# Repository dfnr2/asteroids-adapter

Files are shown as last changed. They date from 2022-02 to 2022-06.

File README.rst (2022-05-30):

Asteroids PCB -> Asteroids Deluxe Cabinet (and vice versa) Adapter
==================================================================

Background
----------

It is occasionally desirable to use an Asteroids PCB in an Asteroids Deluxe
cabinet (or vice versa). For example, the Braze Asteroids Multigame adapter
offers some advantages over the Asteroids Deluxe version of the multigame, such
as more accurate sound, and a Lunar Lander thruster interface. Or one may want
to use an Asteroids cabinet for testing both Asteroids and Asteroids Deluxe
PCBs. Or one may prefer the aesthetics of one cabinet, but the gameplay of the
other PCB.

The Asteroids PCB is almost compatible with the Asteroids Deluxe cabinet (and
vice versa). There are a few differences that must be addressed for an Asteroids
PCB to properly work in an Asteroids Deluxe cabinet:

#. The Deluxe cabinet uses a mirror to produce a floating 3D effect, which has the
   side effect of inverting the image along the Y axis, so Asteroids Y output needs
   to be inverted to properly work on an Asteroids Deluxe cabinet.

#. The Y-axis flip is only true for full standup cabinets. An Asteroids in an
   Asteroids Deluxe Cabaret does not require a flip.

#. The audio amplifier board in the Asteroids Deluxe PCB (A/R 1 board) has a
   voltage gain of 1, while the amplifier in the original Asteroids cabinet (A/R
   board) has a voltage gain of 10. As a result, the Asteroids PCB audio output
   is 1/10 the amplitude of the Asteroids Deluxe PCB, and will be much to quiet.
   The Asteroids audio output needs to be amplified by a factor of 10 to sound
   right.

#. Several control inputs are swapped.  These are:

   - COINL (left coin switch) and START2 (2-player START)

   - COINC (center coin switch) and START1 (1-player START)

   - ROT L (Rotate Left) and ROT R (Rotate Right)

For using an Asteroids Deluxe PCB in an Asteroids cabinet, There is a slightly
different set of considerations:

#. The Asteroids cabinet does not ground the INV_Y input of the Asteroids Deluxe
   PCB, since the Asteroids PCB has no INV_Y input. Therefore, the Y output is
   not inverted, and does not need to be re-inverted by the cabinet.

#. The Astroids Deluxe audio output amplitude will be too large, and needs to be
   divided by 10 to sound correct in an Asteroids cabinet.

#. The control inputs need to be flipped the same as for an Asteroids PCB in an
   Asteroids Cabinet.

The Adapter
-----------

.. _production_package: https://github.com/dfnr2/asteroids-adapter/tree/main/production-package/

The adapter was created with KiCad 6.0.5. KiCad was used because it is freely
available and multi-platform. The adapter design files are in the top directory.
For those who wish to produce the PCB without installing KiCad, a ZIP file is
available in the production_package_ directory.

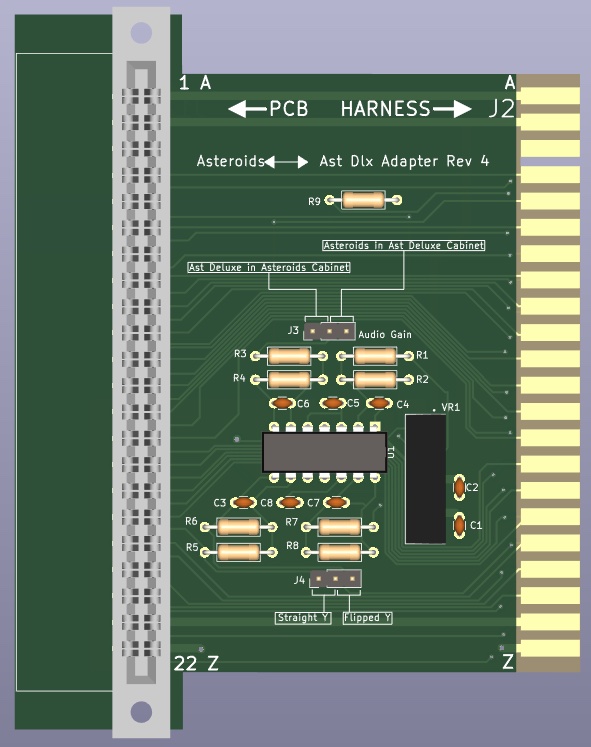
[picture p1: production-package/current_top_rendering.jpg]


Assembly Notes
--------------

The PCB is designed to accomodate a variety of 44-pin edge connectors, so that almost any standard 0.156" connector will work.

- Vertical (straight) edge connectors (such as EDAC 305-044-521-202) can be
  sourced cheaply and are readily available. With a vertical connector, the
  adapter will be perpendicular to the Asteroids PCB.

- A Right-angle edge connector (such as EDAC 307-044-558-201) can be used to
  keep the adapter parallel and aligned the Asteroids PCB. These connectors are
  in production, but as far as I know are only available from EDAC, and could
  potentially be subject to supply chain issues.

Configuration
-------------

The asteroids adapter will accommodate either an Asteroids PCB in an Asteroids
Deluxe Cabinet, or an Asteroids Deluxe PCB in an Asteroids cabinet.

For Asteroids in a Deluxe cabinet, set the jumpers as follows:

- J3 (Audio gain): Asteroids in Ast Dlx Cabinet (10x gain)

- J4 (Y Flip): Flipped Y

For Asteroids Deluxe in an Asteroids cabinet, set the jumpers as follows:

- J3 (Audio gain): Ast Dlx in Asteroids Cabinet (0.1x gain)

- J4 (Y Flip): Straight Y

For Asteroids in an Asteroids Deluxe cabaret cabinet (not tested):

- J3 (Audio gain): Asteroids in Ast Dlx Cabinet (10x gain)

- J4 (Y Flip): Straight Y

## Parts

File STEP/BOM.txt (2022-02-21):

3DX_CUI_Supplier: CUI, Inc
3DX_CUI_Description: 15 Vdc, 0.067 A, 1 W, 4.5 ~ 5.5 Vdc Input Range
3DX_CUI_Model Number: PESE1-S5-S15-M

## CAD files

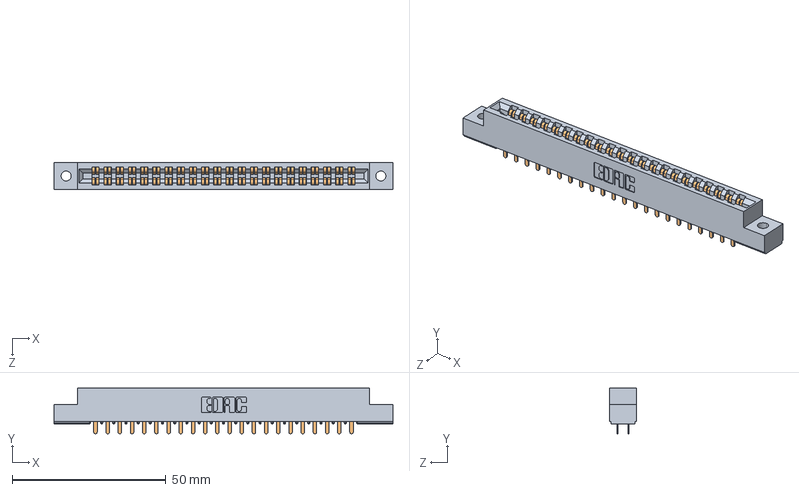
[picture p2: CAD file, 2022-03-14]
STEP/EDAC-305-44-0521-202.STEP
110.2 x 14.9 x 8.71 mm
305 Part_.128 Dia

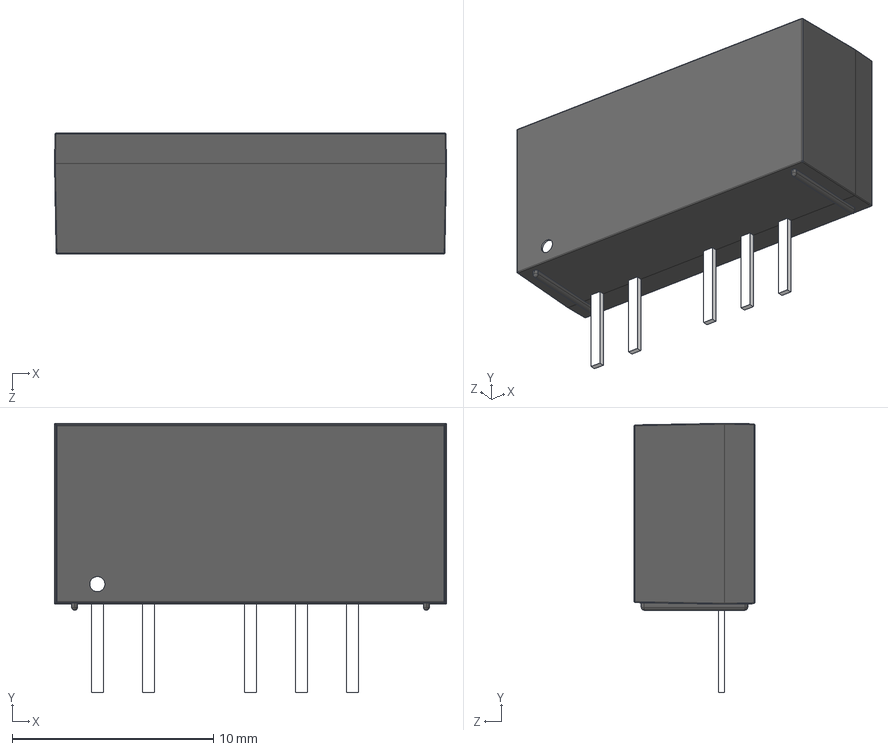
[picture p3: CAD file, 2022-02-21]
STEP/PDM1-S5-D15-S.step
19.5 x 13.4 x 6.00 mm

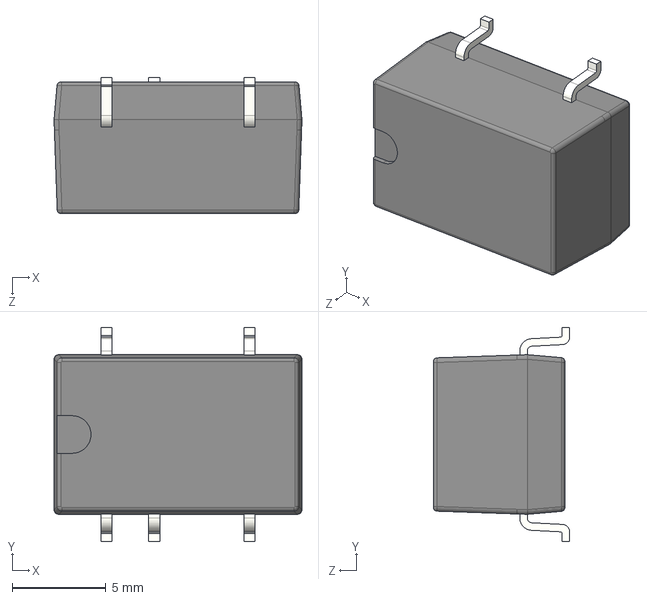
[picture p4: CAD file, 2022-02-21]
STEP/CUI_PESE1-S5-S15-M.step
13.2 x 11.4 x 7.25 mm

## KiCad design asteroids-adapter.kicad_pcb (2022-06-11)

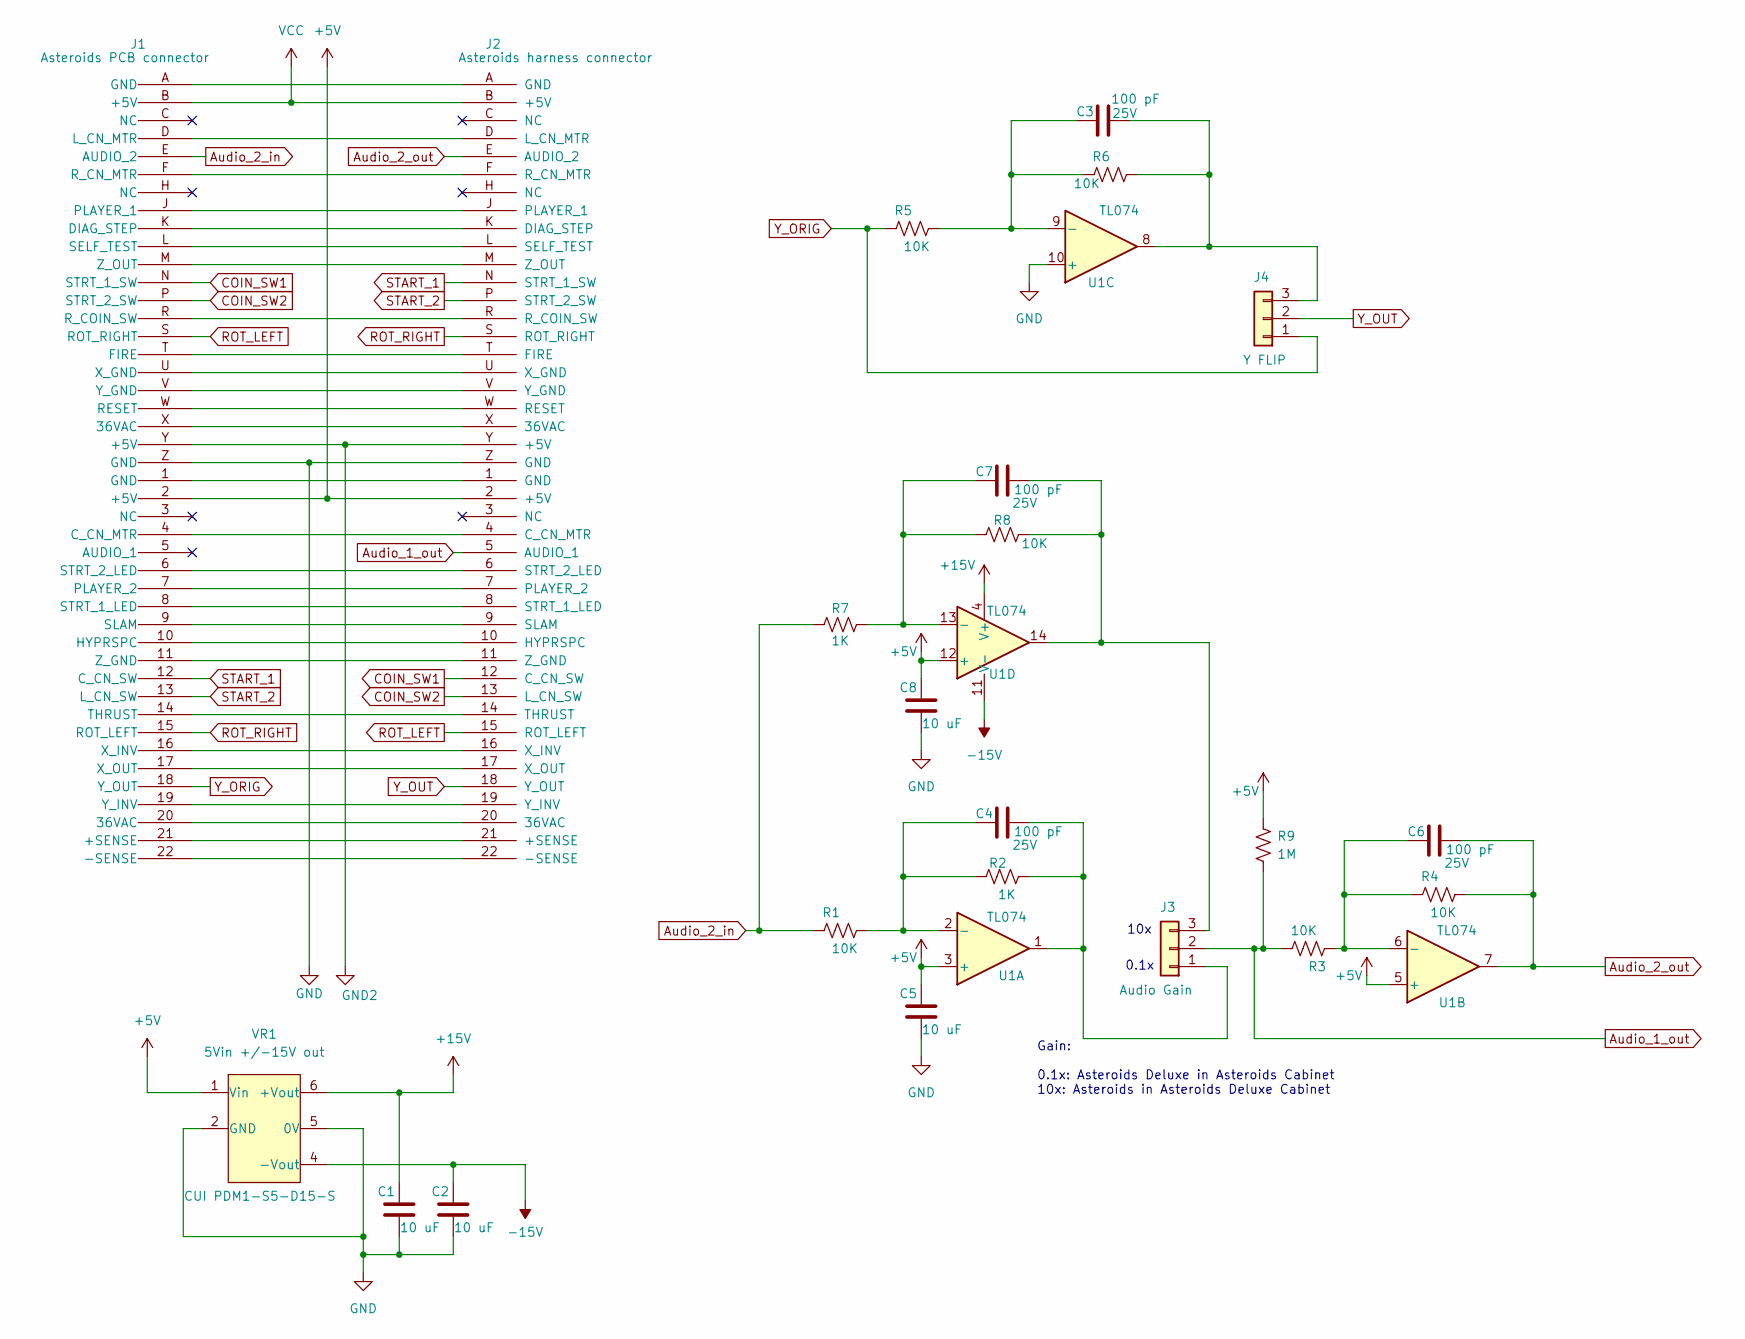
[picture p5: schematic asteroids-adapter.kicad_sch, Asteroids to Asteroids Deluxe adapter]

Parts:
C1, C2, C5, C8: Kemet 10 uF 25V MLCC TH; C_Disc_D3.0mm_W1.6mm_P2.50mm; Tolerance If applicable; Power Rating If applicable; Manufacturer PN C320C475K3N5TA91707301
C3, C4, C6, C7: Kemet MLCC 100 pF 5% 25V TH; C_Disc_D3.0mm_W1.6mm_P2.50mm; Tolerance 5%; Voltage Rating 25V; Manufacturer PN C315C101J3G5TA
J1: Asteroids PCB connector; EDAC 44-pin edge 0.156 universal; Tolerance n/a; Current Rating 5A; Manufacturer PN 307-044-558-201
J2: Asteroids harness connector; edge 44-pin 0.156 inch
J3: Audio Gain; PinHeader_1x03_P2.54mm_Vertical; Tolerance If applicable; Current Rating 3A; Manufacturer PN 2303-6111TG
J4: Y FLIP; PinHeader_1x03_P2.54mm_Vertical; Tolerance If applicable; Current Rating 3A; Manufacturer PN 2303-6111TG
R1, R3, R4, R5, R6, R8: Yageo 10K ohm 1% thin film TH; R_Axial_DIN0207_L6.3mm_D2.5mm_P10.16mm_Horizontal; Tolerance 1%; Power Rating 1/4 W; Manufacturer PN MFR-25FTE52-10K
R2, R7: Yageo 1K ohm 1% thin film TH; R_Axial_DIN0207_L6.3mm_D2.5mm_P10.16mm_Horizontal; Tolerance 1%; Power Rating 1/4 W; Manufacturer PN MFR-25FTE52-1K
R9: Yageo 1Mohm 1% thin film TH_1; R_Axial_DIN0207_L6.3mm_D2.5mm_P10.16mm_Horizontal; Tolerance 1%; Power Rating 1/4 W; Manufacturer PN MFR-25FTE52-1M
U1: TL074; DIP-14_W7.62mm; Tolerance If applicable; Power Rating If applicable; Manufacturer PN MFG PN
VR1: CUI PDM1-S5-D15-S; CONV_PDM1-S5-D15-S; Power Rating If applicable; Manufacturer PN PDM1-S5-D15-S

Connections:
+5V: C5.2, C8.2, J1.2 (+5V), J2.2 (+5V), R9.1, U1.3 (+), U1.5 (+), U1.12 (+), VR1.1 (Vin)
+15V: C1.2, U1.4 (V+), VR1.6 (+Vout)
-15V: C2.2, U1.11 (V-), VR1.4 (-Vout)
Audio_1_out: J2.5 (AUDIO_1), J3.2, R3.1, R9.2
Audio_2_in: J1.E (AUDIO_2), R1.2, R7.1
Audio_2_out: C6.2, J2.E (AUDIO_2), R4.1, U1.7
COIN_SW1: J1.N (STRT_1_SW), J2.12 (C_CN_SW)
COIN_SW2: J1.P (STRT_2_SW), J2.13 (L_CN_SW)
GND: C1.1, C2.1, C5.1, C8.1, J1.Z (GND), J2.Z (GND), U1.10 (+), VR1.2 (GND), VR1.5 (0V)
GND2: J1.Y (+5V), J2.Y (+5V)
unnamed: C3.1, R5.1, R6.2, U1.9 (-)
unnamed: C3.2, J4.3, R6.1, U1.8
unnamed: C4.1, R1.1, R2.2, U1.2 (-)
unnamed: C4.2, J3.1, R2.1, U1.1
unnamed: C6.1, R3.2, R4.2, U1.6 (-)
unnamed: C7.1, R7.2, R8.1, U1.13 (-)
unnamed: C7.2, J3.3, R8.2, U1.14
unnamed: J1.1 (GND), J2.1 (GND)
unnamed: J1.4 (C_CN_MTR), J2.4 (C_CN_MTR)
unnamed: J1.6 (STRT_2_LED), J2.6 (STRT_2_LED)
unnamed: J1.7 (PLAYER_2), J2.7 (PLAYER_2)
unnamed: J1.8 (STRT_1_LED), J2.8 (STRT_1_LED)
unnamed: J1.9 (SLAM), J2.9 (SLAM)
unnamed: J1.10 (HYPRSPC), J2.10 (HYPRSPC)
unnamed: J1.11 (Z_GND), J2.11 (Z_GND)
unnamed: J1.14 (THRUST), J2.14 (THRUST)
unnamed: J1.16 (X_INV), J2.16 (X_INV)
unnamed: J1.17 (X_OUT), J2.17 (X_OUT)
unnamed: J1.19 (Y_INV), J2.19 (Y_INV)
unnamed: J1.20 (36VAC), J2.20 (36VAC)
unnamed: J1.21 (+SENSE), J2.21 (+SENSE)
unnamed: J1.22 (-SENSE), J2.22 (-SENSE)
unnamed: J1.A (GND), J2.A (GND)
unnamed: J1.D (L_CN_MTR), J2.D (L_CN_MTR)
unnamed: J1.F (R_CN_MTR), J2.F (R_CN_MTR)
unnamed: J1.J (PLAYER_1), J2.J (PLAYER_1)
unnamed: J1.K (DIAG_STEP), J2.K (DIAG_STEP)
unnamed: J1.L (SELF_TEST), J2.L (SELF_TEST)
unnamed: J1.M (Z_OUT), J2.M (Z_OUT)
unnamed: J1.R (R_COIN_SW~), J2.R (R_COIN_SW~)
unnamed: J1.T (FIRE), J2.T (FIRE)
unnamed: J1.U (X_GND), J2.U (X_GND)
unnamed: J1.V (Y_GND), J2.V (Y_GND)
unnamed: J1.W (RESET), J2.W (RESET)
unnamed: J1.X (36VAC), J2.X (36VAC)
ROT_LEFT: J1.S (ROT_RIGHT), J2.15 (ROT_LEFT)
ROT_RIGHT: J1.15 (ROT_LEFT), J2.S (ROT_RIGHT)
START_1: J1.12 (C_CN_SW), J2.N (STRT_1_SW)
START_2: J1.13 (L_CN_SW), J2.P (STRT_2_SW)
VCC: J1.B (+5V), J2.B (+5V)
Y_ORIG: J1.18 (Y_OUT), J4.1, R5.2
Y_OUT: J2.18 (Y_OUT), J4.2

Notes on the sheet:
0.1x
10x
Gain: 0.1x: Asteroids Deluxe in Asteroids Cabinet 10x: Asteroids in Asteroids Deluxe Cabinet

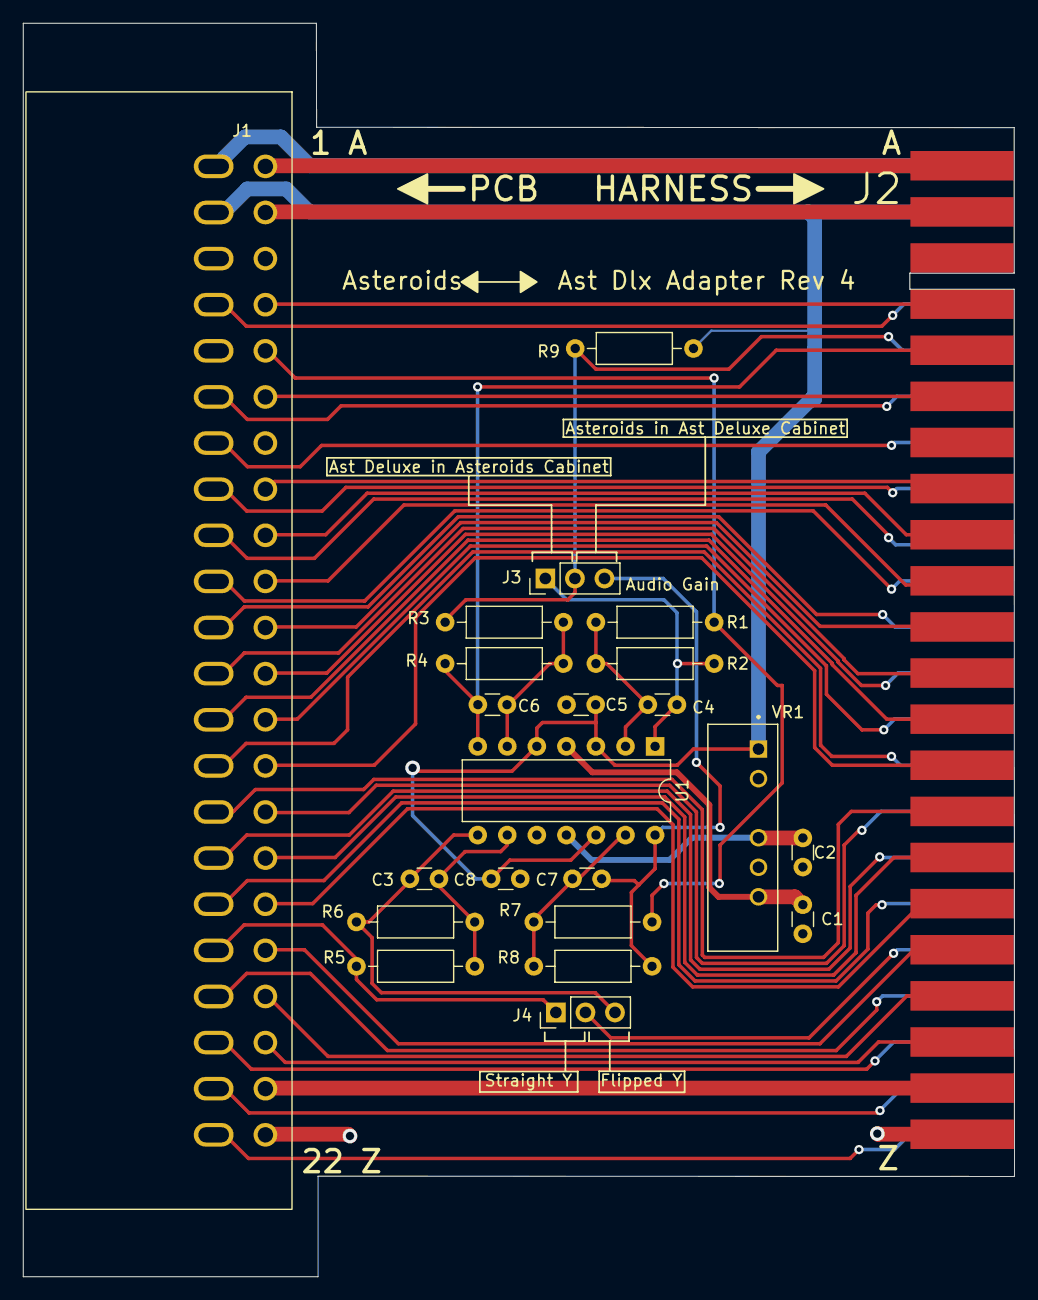
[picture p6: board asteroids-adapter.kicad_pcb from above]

Board: 2 copper layers, 85.2 x 107.7 mm, 23 parts (0 on the bottom side), 52 nets.

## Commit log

2022-02-21 Rev 1 of Asteroids PCB -> Ast Deluxe Cab adapter
    [asteroids-adapter.kicad_pcb, asteroids-adapter.kicad_sch]
2022-02-21 Fixed DC-DC footprint and silk screen info
    - Downloaded from CUI website
    - fixed connector labels
    [CUI_PESE1-S5-S15-M.step, asteroids-adapter.kicad_pcb, asteroids-adapter.kicad_sch]
2022-02-21 Make sure all the caps have library symbols
    [asteroids-adapter.kicad_pcb, asteroids-adapter.kicad_sch]
2022-02-21 Replace SMT DC/DC converter with Through-hole Part
    Retro hobbyists prefer through hole.
    [PDM1-S5-D15-S.step, asteroids-adapter.kicad_pcb, asteroids-adapter.kicad_sch]
2022-02-21 Add part number to DC DC converter
    [asteroids-adapter.kicad_sch]
2022-02-22 No solder mask around the edge connectors.
    - Original footprint had wrong solder mask layer for bottom layer pads.
    Fixed, and also place solder mask keepout over entire length of the
    edge connectors
    - Trimmed ground pour to prevent "fingers" extending between edge
    connector pads.
    [asteroids-adapter.kicad_pcb, asteroids-adapter.kicad_sch]
2022-02-24 Power and GND to DC-DC converter were swapped
    Fixed by swapping the power and ground connections to pins 1 and 2 of
    the DC-DC converter.
    [asteroids-adapter.kicad_pcb, asteroids-adapter.kicad_sch]
2022-02-24 Track went between edge connectors
    Moved track off of edge connector region.
    [asteroids-adapter.kicad_pcb]
2022-02-24 widen no-soldermask zone around edge connectors
    - widened the f-mask and b-mask rectangles in footprint
    - updated footprints in PCB
    - moved some pads outside of no-mask zones
    [asteroids-adapter.kicad_pcb]
2022-02-24 Update to rev 1.3
    [asteroids-adapter.kicad_pcb, asteroids-adapter.kicad_sch]
2022-02-24 Add bypass to 5V op-amp reference
    - Added 10 uf cap at (+) input of both audio inverter op amps, to reduce
    noise.
    [asteroids-adapter.kicad_pcb, asteroids-adapter.kicad_sch]
2022-03-08 Move parts for narrower design
    - Still need to move connector and finish re-routing
    [asteroids-adapter.kicad_pcb]
2022-03-08 squashed PCB
    Still need to clean up PCB outline and re-route
    [asteroids-adapter.kicad_pcb]
2022-03-09 Completed routing on compact PCB
    [asteroids-adapter.kicad_pcb, asteroids-adapter.kicad_sch]
2022-03-09 Rearranged config silk screen table
    - easier to understand row format.
    - white boxes to mark selected configuration.
    [asteroids-adapter.kicad_pcb, asteroids-adapter.kicad_sch]
2022-03-14 Swith to PCB-mount edge connector
    This is easier to assemble and provides a more reliable connection, due
    to reduced likelyhood of distorting the edge connector position.
    [EDAC-305-44-0521-202.STEP, asteroids-adapter.kicad_pcb, asteroids-adapter.kicad_sch]
2022-03-14 Added connections for X_INV and Y_INV
    [asteroids-adapter.kicad_pcb, asteroids-adapter.kicad_sch]
2022-03-14 Add jumper for configuration
    Configure unused opamp as 0.1x gain, and add jumper to select between
    10x and 0.1x gain audio.
    [asteroids-adapter.kicad_pcb, asteroids-adapter.kicad_sch]
2022-03-15 Fixed jumper to 0.1" 3-pin header
    also silk screen fixed
    [asteroids-adapter.kicad_pcb, asteroids-adapter.kicad_sch]
2022-05-14 Fixed audio output selection
    Audio 1 was always connected to the x10 gain amplifier, instead of the
    gain selected by the jumper.
    Also, fixed the 3-pin header in the schematic to use the correct 2.54mm
    pitch part.
    [asteroids-adapter.kicad_pcb, asteroids-adapter.kicad_sch]
2022-05-15 Universal connector
    Update connector footprint to accommodate 0.2 and 0.156 row spacing, and
    vertical or right-angle connectors.
    Update more parts with full parameters
    Add 1M resistor to pin 2 of jumper, so op-amp input isn't floating if
    jumper is left out.
    [asteroids-adapter.kicad_pcb, asteroids-adapter.kicad_sch]
2022-05-15 Added library item for 3-pin connector
    Need full params for all items to make a BOM.
    [asteroids-adapter.kicad_sch]
2022-05-16 Clean up Makefiles and BOM generation
    - Makefiles auto-generate README files
    - Fix part parameters and BOM configuration
    [asteroids-adapter.kicad_pcb, asteroids-adapter.kicad_sch]
2022-05-19 Updated component fields in PCB
    [asteroids-adapter.kicad_pcb]
2022-05-20 Added FLIP Y jumper
    FLIP Y provides required for AST Deluxe in AST cab, and also for
    Asteroids in a Deluxe cabaret cabinet.
    Added 2-pin header to library
    More makefile tweaks.
    [asteroids-adapter.kicad_pcb, asteroids-adapter.kicad_sch]
2022-05-21 More cleanups and bump version
    - Cleaned up schematic to align components to grid
    - Added bypass cap on 0.1x gain input
    - More Makefile cleanups
    [asteroids-adapter.kicad_pcb, asteroids-adapter.kicad_sch]
2022-05-30 Fixes for Dlx in Ast cabinet
    - Fixed reversed opamp inputs to the 0.1x gain audio path
    - Changed the implementation of the "Y flip" jumper. Now the jumper
    selects the original signal or the reversed signal, rather than
    grounding the "INV_Y" line. This results in a more predictable result.
    I.e., Moving the jumper will always flip the Y axis, while a jumper that
    grounds "INV_Y" will have no effect if the line is grounded elsewhere in
    the system.
    - Bumped version to 4.0
    - Thanks to Michael W. for testing the adapter with an Asteroids Deluxe
    PCB in an Asteroids Cabinet.
    [asteroids-adapter.kicad_pcb, asteroids-adapter.kicad_sch]
2022-05-30 Updated README and Makefile
    - README includes a Makefile-generated link to the PCB rendering,
    instead of hard-coding the filename in the README, since the name
    changes with the revision number.
    Add link to rendering
    Replace link to rendering with a copy
    README uses version-independent link to image
    To avoid changing the README every rev bump, make a copy of the top
    rendering without the rev number, and include that copy instead.
    It would be preferable to generate an include file calling out the
    current rendering, but apparently Github won't allow include files in
    the README.
    Add assembly notes with connector part numbers
2022-06-11 Swapped amplifier gains in schem to match pcb
    - In Rev 4, the PCB silk screen reversed the labels for J3, "Asteroids in
    Ast Deluxe Cabinet" and "Ast Deluxe in Asteroids Cabinet". Since some
    PCBs were already made, the solution is to swap the resistor values in
    the schematic to make the J3 labels correct, so no PCB change is needed
    and no respin required.
    - Bump the schematic rev to 4.1. PCB remains at rev 4
    - updated Makefiles to latest version.
    [asteroids-adapter.kicad_pcb, asteroids-adapter.kicad_sch]
